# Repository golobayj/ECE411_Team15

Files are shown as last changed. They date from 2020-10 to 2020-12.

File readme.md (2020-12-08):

# ECE411 Team 15 Practicum Project

## Links To Documentation:

### [Project_Design_Specification.pdf](docs/Project_Design_Specification.pdf)

### [Practicum_Project_Ideas.pdf](docs/Practicum_Project_Ideas.pdf)

### [Functional_Decomposition.pdf](docs/Functional_Decomposition.pdf)

### [Modeling.pdf](docs/Modeling.pdf)

### [Test_Plan.pdf](docs/Test_Plan.pdf)

## Final Designs:

### Demo
[Demo Video](https://drive.google.com/file/d/1zAOsdVPUFq6oVJJ1poNx3nirWUGRS5xu/view?usp=sharing)

### Schematic rev 1.1
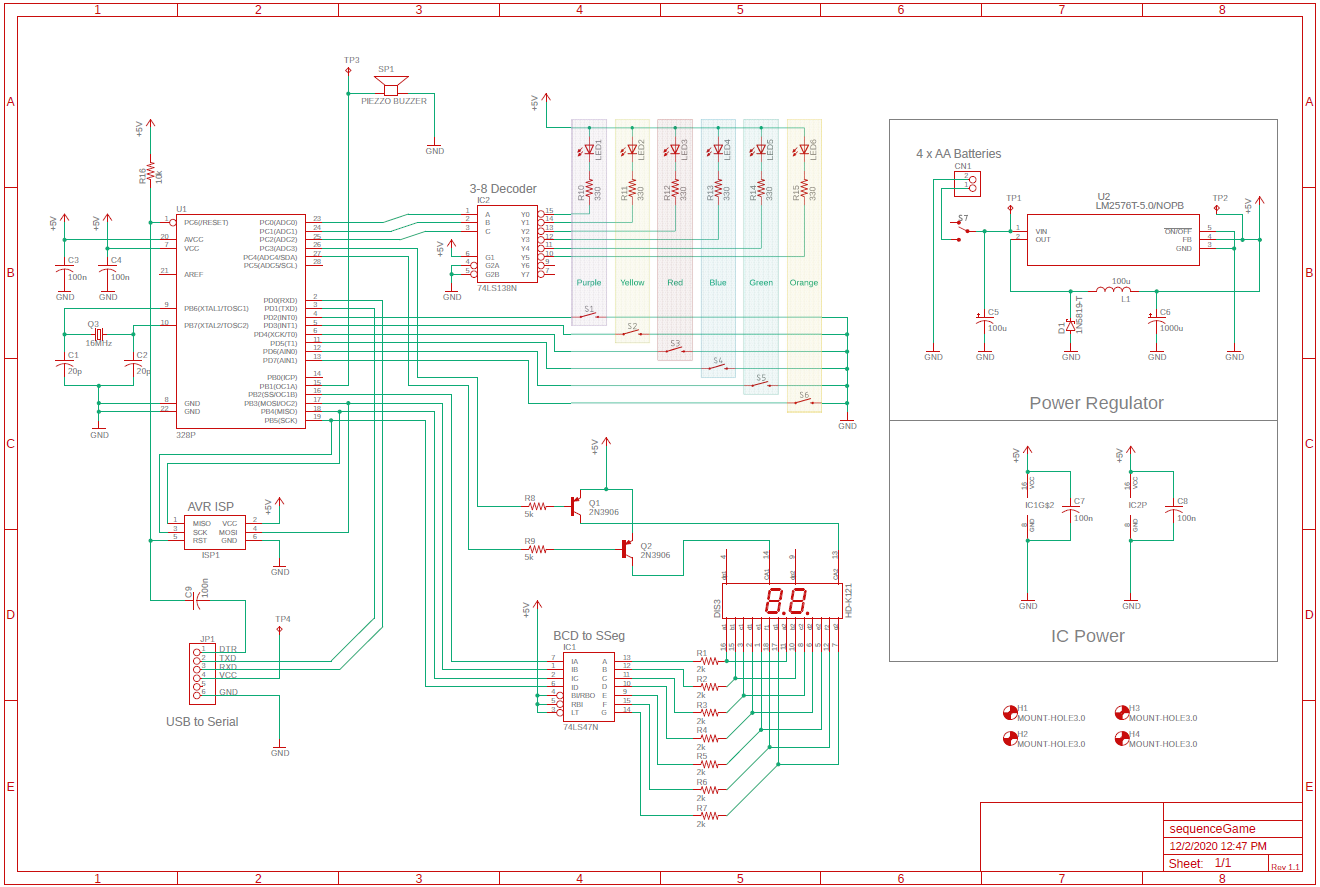
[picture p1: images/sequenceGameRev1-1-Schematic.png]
SchematicRev1-0


### PCB Layout rev 1.0
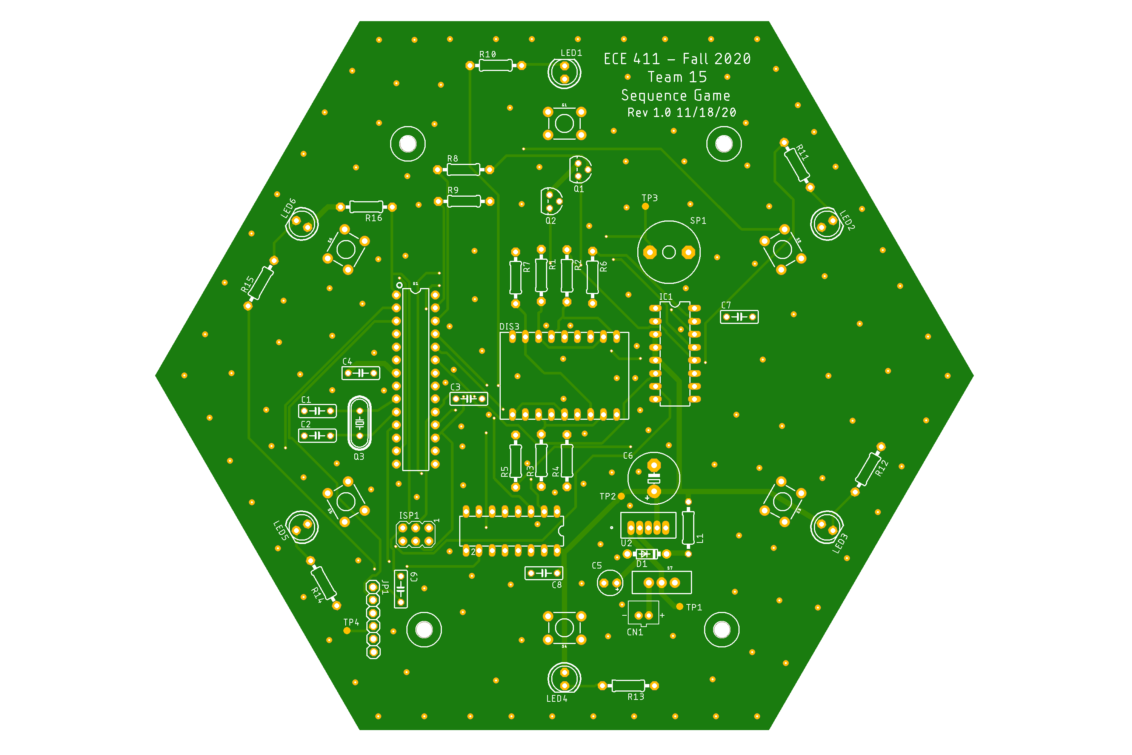
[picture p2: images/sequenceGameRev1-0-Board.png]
BoardRev1-0


### Physical Design
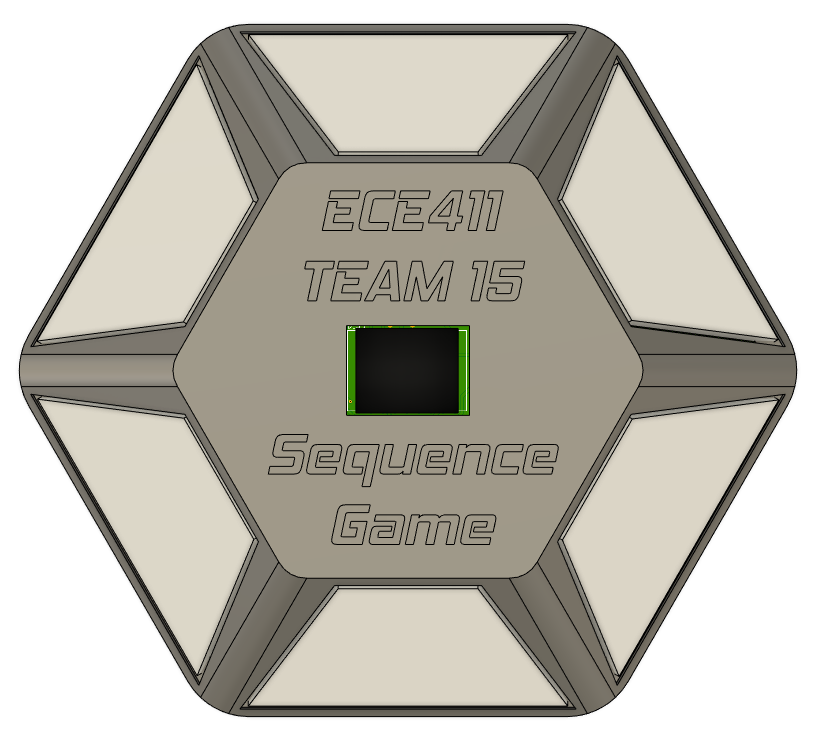
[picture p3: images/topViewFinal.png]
topViewFinal


## Preliminary Designs:

### Breadboard
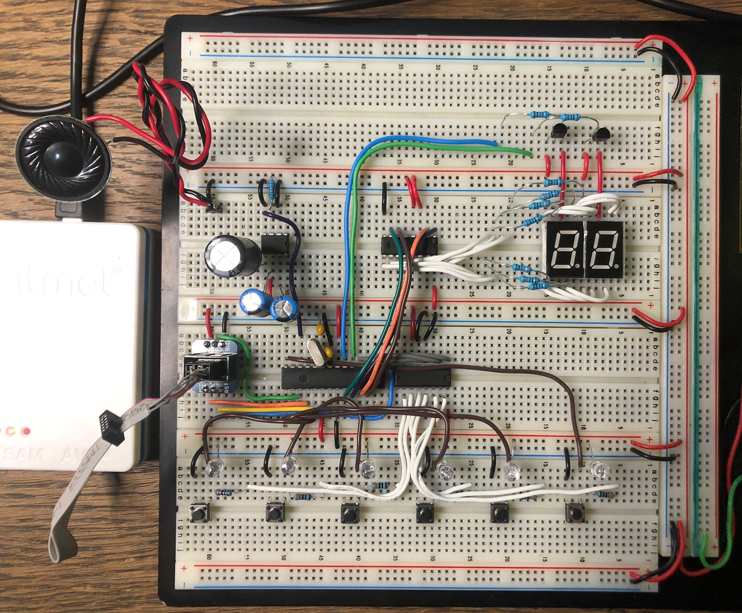
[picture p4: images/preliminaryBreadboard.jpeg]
preliminaryBreadboard


### Physical Design
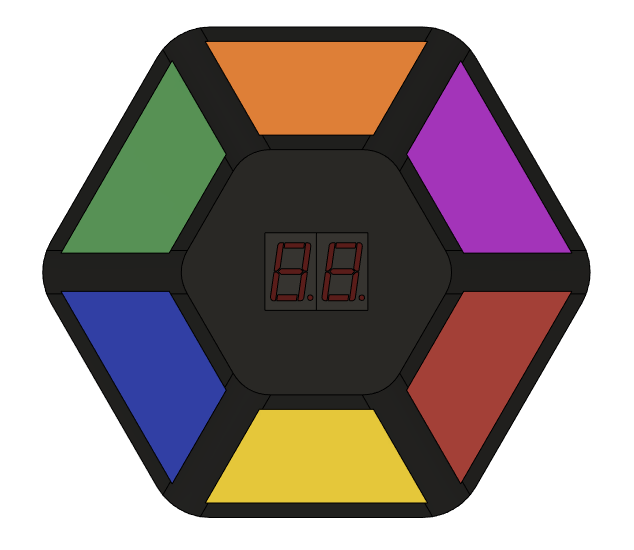
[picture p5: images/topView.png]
topView

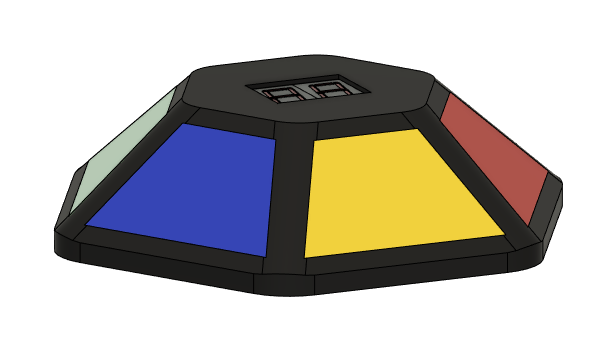
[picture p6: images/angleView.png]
angleView


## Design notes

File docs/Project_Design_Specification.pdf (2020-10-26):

# Team 15 Product Design Specification

## Executive Summary

This project is a simple electronic sequence-based memory game. The game works by displaying a randomly generated sequence of lights and tones that correlate to specific buttons on the device. The game player then attempts to input the same sequence as displayed. The sequence starts at a length of 1 and increases by 1 with each successful matched sequence input by the player. When the player inputs an incorrect sequence the game ends and reports the length of the final correct sequence. Each time the game is played a new random sequence will be generated. Multiplayer mode will allow players to take turns against one another until a player inputs the incorrect sequence.

## Brief Market Analysis

Our product mainly targets parents who are looking for a game that helps their children develop memorization abilities while having fun. Parents and adults may even find it enjoyable and it may have a nostalgic appeal to people familiar with the similar memory game known as Simon.

Similar classic Simon games and other memory related toys that are already out there on the market these would become our primary competition. We decided to make our product with more add-on features to enhance user’s experience with the game compared to classic version. Those features include two extra sides with original design (total of 6 sided compared to 4 sided classic toy), a 7 segment display screen to report player’s score, which is useful to make challenges with friends, various difficulty levels, and multiplayer support.

Additional features may be explored during development. The price range for the Simon games currently found on the market are around $20-30. We estimate the price point for our design to be reasonably estimated at $20. As we finalize the design and components we will adjustment the price accordingly.

## Requirements

The device must be assembled on a 2 or more layer printed circuit board, with a microcontroller to accurately record the user’s inputs and their score. The device will have 6 buttons that will serve as inputs, as well as 6 LEDs which will correspond to each of the buttons.

The system must have a way to accurately keep track of what buttons the user presses. The device must have a randomized sequence of colored buttons each time the game is played. Upon startup, the device may have a short animation using the light displays.

The device should hold the user’s attention for at least one game. The difficulty of the game may be togglable by the user based on their preference or skill level. A multiplayer mode may be included to expand potential gameplay options.

The system will have a speaker to make a distinct sound for each button that is pressed, and the speaker may notify the user of the number of rounds they have successfully passed. The speaker may also be used to play startup tones, or a tone when the user reaches a certain benchmark.

The device must be portable and untethered, using batteries as the source of power for the system. The batteries should last for at least 100 games before needing to be changed out. The device should have an accessible battery compartment for maintenance, while all of the other parts of the device should be permanently fixed onto the device.

As a whole, the device should be durable and able to withstand minor impacts. The unit will also have a power switch to turn the device on and off. The device should be comfortable to hold and use, with rounded edges and corners, and must not cause harm to the user. The device will not infringe on any patents or copyrights.

## System Architecture

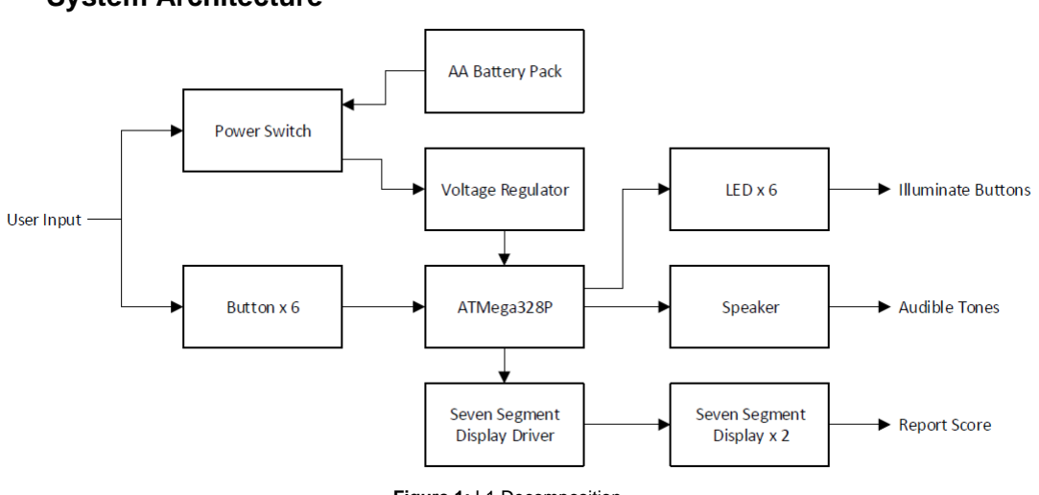
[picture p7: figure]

## Design Specifications

- Processor: Atmel ATMega328P
- Clock: 16MHz external crystal oscillator
- Sensors: 6 x push buttons, power switch
- Actuators: 6 x LEDs, 2 x seven segment displays, speaker
- Power: AA Batteries with voltage regulator
- Firmware: Embedded C
- Development Environment: Atmel Studio 7, Github Repository

Figure 1: L1 Decomposition

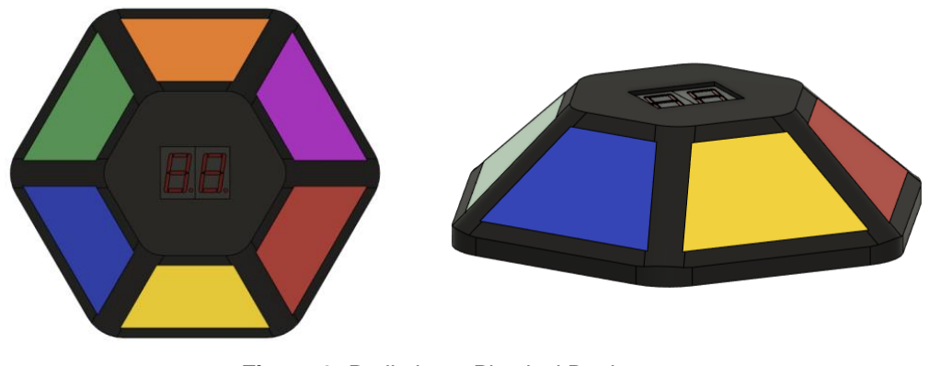
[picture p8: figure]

Figure 2: Preliminary Physical Design

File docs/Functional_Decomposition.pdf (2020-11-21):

ECE 411 | Functional Decomposition | Rev 1.0
Team 15 | | 11/20/20

# Sequence Memory Game: Level 0

## Sequence

## Memory Game

6

Power, Nominal 6V DC

Color Button Inputs

6

Color LED Outputs

Score Display

Audible Tones

Module | Sequence Memory Game
Inputs | Power: Nominal 6V DC provided by 4 x AA Batteries Color Buttons: 6 Buttons corresponding to 6 different colors (red, yellow, orange, green, blue, purple)
Outputs | Audible Tones: Passive piezo buzzer to generate tones that correlate to colors Seven Segment Display: Reports current score to the user Color LEDs: 6 LEDS to correspond to button colors
Functionality | Game that generates a pseudorandom sequence where each element corresponds to a colored LED and tone. Sequence is output starting at length of one and increases in length by one each round. User attempts to input the correct sequence using buttons of corresponding colors to advance to the next round and set the high score.

# Sequence Memory Game: Level 1

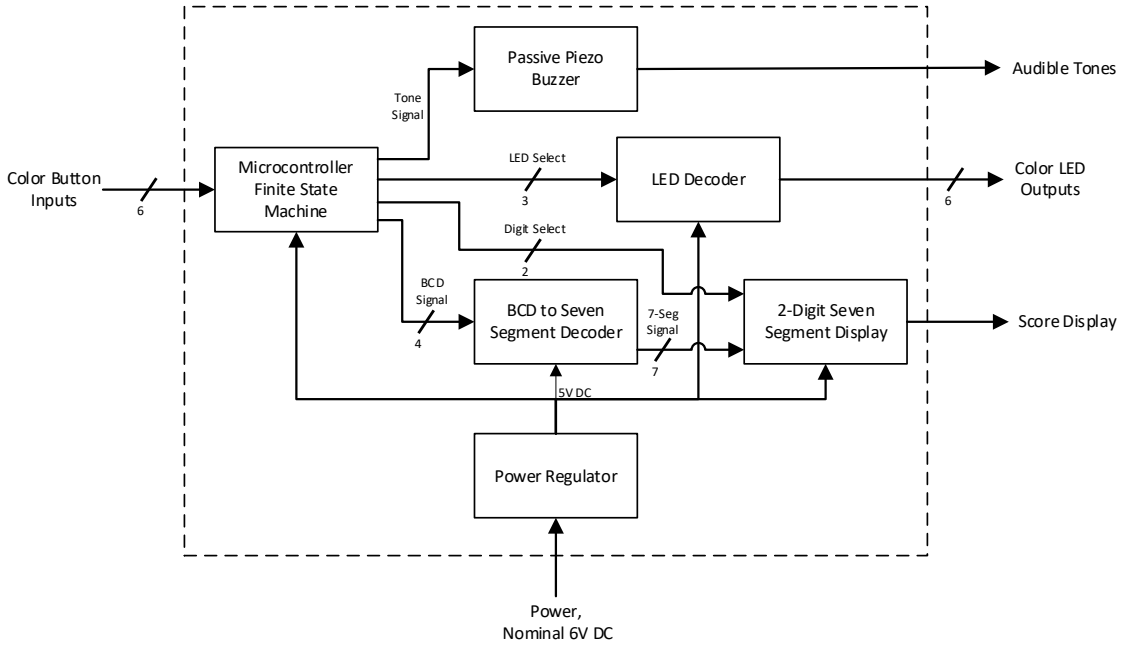
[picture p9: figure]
Microcontroller Finite State Machine; Passive Piezo Buzzer; BCD to Seven Segment Decoder; 2-Digit Seven Segment Display; Power Regulator; LED Decoder; Audible Tones; Color LED Outputs Color Button Inputs; Score Display; Power, Nominal 6V DC; BCD Signal; 7-Seg Signal; Digit Select; LED Select; Tone Signal

# Microcontroller Finite State Machine: Level 1

Microcontroller
Finite State Machine

3

4

6
2

Color Button Inputs

Tone Signal
LED Select
Digit Select
BCD Signal

5V DC

Module | Microcontroller Finite State Machine
Inputs | 5V DC: Regulated 5V DC provided from power regulator module Color Buttons: 6 Buttons corresponding to 6 different colors (red, yellow, orange, green, blue, purple)
Outputs | Tone Signal: Output signal to drive passive piezo buzzer with tones LED Select: 3-bit signal to select appropriate color LED Digit Select: 2-bit signal to select digit of seven segment display BCD Signal: 4-bit BCD signal to output value of seven segment display digit
Functionality | Finite State Machine that is hosted on a microcontroller that drives current state of game. The LED and tone signals are used to output the sequence and acknowledge user input. The seven segment signals are used to report to the user the score of the game. States used are Idle, Start, Display Sequence, Input Sequence, Win, and Lose.

# Passive Piezo Buzzer: Level 1

Tone Signal | Passive Piezo Buzzer | Audible Tones
Module | Passive Piezo Buzzer
Inputs | Tone Signal: Input signal from the microcontroller that drives the tone at a specific frequency
Outputs | Audible Tones: Tones that correspond with the 6 different colored buttons
Functionality | Outputs a tone that is driven by the tone signal from the microcontroller. Tones are of a specific frequency to correspond with a specific color in the sequence or the state of the game. For example, when the player inputs an incorrect sequence a low tone is output.

# LED Decoder: Level 1

LED Decoder

3 | 6
LED Select | Color LED Outputs

5V DC

Module | LED Decoder
Inputs | 5V DC: Regulated 5V DC provided from power regulator module LED Select: 3-bit signal to select appropriate color LED
Outputs | Color LEDs: 6 LEDS to correspond to button colors
Functionality | Decodes 3-bit LED select signal to drive one of 6 colored LEDs that correspond with the respective color of the sequence displayed or the button input by the user.

# BCD to Seven Segment Decoder: Level 1

BCD to Seven Segment
Decoder
4 | 7

5V DC

BCD Signal | Seven Segment Signal
Module | BCD to Seven Segment Decoder
Inputs | 5V DC: Regulated 5V DC provided from power regulator module BCD Signal: 4-bit BCD signal to select value of seven segment display digit
Outputs | Seven Segment Signal: 7-bit signal that corresponds to each segment A-F of the display
Functionality | Decodes binary coded decimal (BCD) to the proper signals needed to drive the seven segment display with the correct corresponding digits of 0-9.

# 2-Digit Seven Segment Display: Level 1

2-Digit Seven Segment
Display

2

7

5V DC

Digit Select

Seven Segment Signal

Score Display

Module | 2-Digit Seven Segment Display
Inputs | 5V DC: Regulated 5V DC provided from power regulator module Digit Select: 2-bit signal to select digit of seven segment display Seven Segment Signal: 7-bit signal that corresponds to each segment A-F of the display
Outputs | Score Display: Outputs the current score of the game to the user
Functionality | Displays the current round or status of the game to the user by illuminating the segments of the display as determined by the BCD to seven segment module. Time division multiplexing is used to drive only one digit at a time fast enough that to the user both digits appear on at the same time.

# Power Regulator: Level 1

Power Regulator

Power,
Nominal 6V DC

5V DC

Module | Power Regulator
Inputs | Power: Nominal 6V DC provided by 4 x AA Batteries
Outputs | 5V DC: Regulated 5V DC to provide power to the other modules
Functionality | Regulates power from batteries to provide consistent 5V power to the modules in the system that require power.

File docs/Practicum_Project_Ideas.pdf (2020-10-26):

# Team 15 Practicum Project Ideas

Our team has decided to pursue Idea 1 below for our practicum project.

Idea 1: 3D "Simon" Says Game

This project is a game that is similar to "Simon Says". The game works by displaying a sequence of lights and tones that correlate to specific buttons on the device. The game player than attempts to input the same sequence as the device displayed. The sequence starts at a length of 1 and increases by 1 with each successful matched sequence input by the player. When the player inputs an incorrect sequence the game ends and reports the length of the final correct sequence. This project will build on this concept by changing the typical plane of 4 buttons and expand it to a 3D shape such as a cube with 6 buttons or a octahedron with 8 sides. The device will use tactile buttons as sensors. The device will actuate a speaker and LEDs. This project can be implemented using an ATMega328P microcontroller.

Sensor: One button for every side of the object

Actuator: One LED for every button and a speaker for audible tones

Controller: ATMega328P

Idea 2: Cup With Temperature Indicator

This project's main purpose is to display the temperature of a cup and/or the liquid its holding so that the user can drink the liquid at its optimal/preferred temperature. The basic design of the project consists of a cup with a temperature sensor inside. The lower part of the cup would be where the microcontroller is stored. When the temperature of the inside of up shifts by a significant amount, the microcontroller would then save the temperature, and display it on a flexible LCD display on the outside of the cup for the user to read.

Sensor: Temperature Sensors

Actuator: LCD (16x2)

Controller: ATMega328P

Idea 3: Digital Clock

This project is aimed to design an automated system of digital clock and temperature thermometer, which assists people’s need on a daily basis to keep track of time. The problem with a regular digital clock is that we have to set the time manually every time the battery runs out or electric outages and also have to look elsewhere/other devices to know the exact time to set to. Therefore, this clock will come in advantage of helping us set the real time automatically with more accuracy. The basic concept of how this clock works is that it takes in measurements from LM335 and time information stored in DS1307, processes in ATMMega32 microcontroller and then displays these values via LCD 16x2 screen. The DS1307 is chosen because it has a built-in feature that can automatically switch to backup supply to keep track of time when power source outage, which assists our purpose of the project.

Sensor: DS1307/1038 serial real-time clock (RTC), LM335 Precision Temperature Sensors

Actuator: LCD (16x2)

Controller: ATMega328P

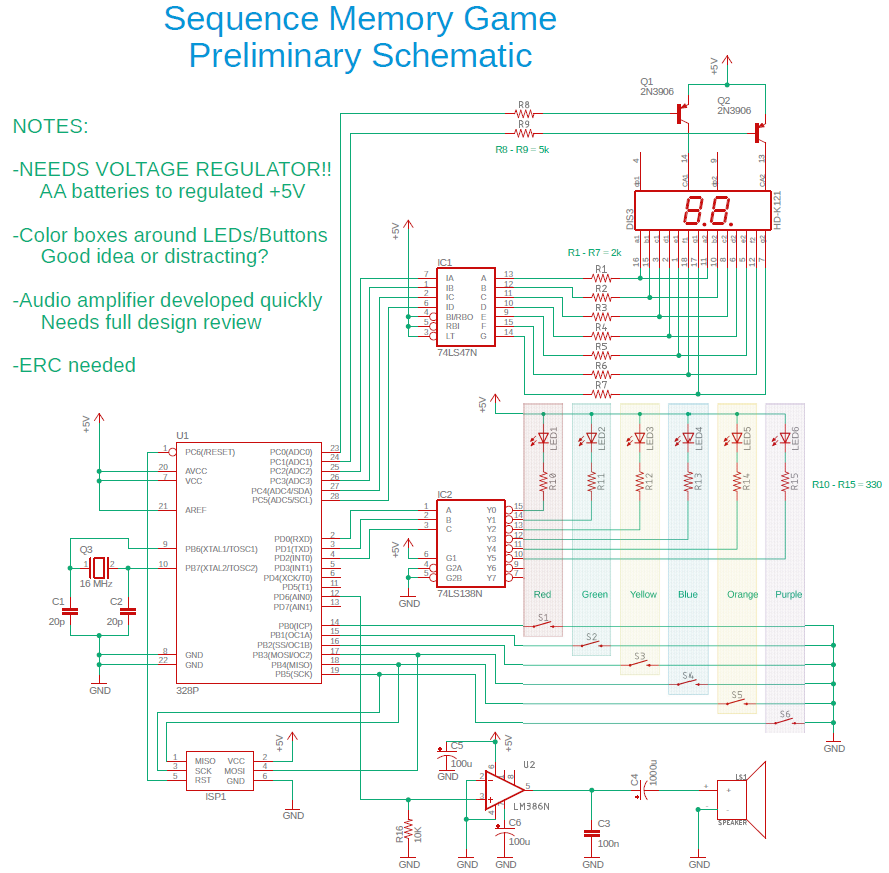
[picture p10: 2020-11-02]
images/preliminarySchematic.png

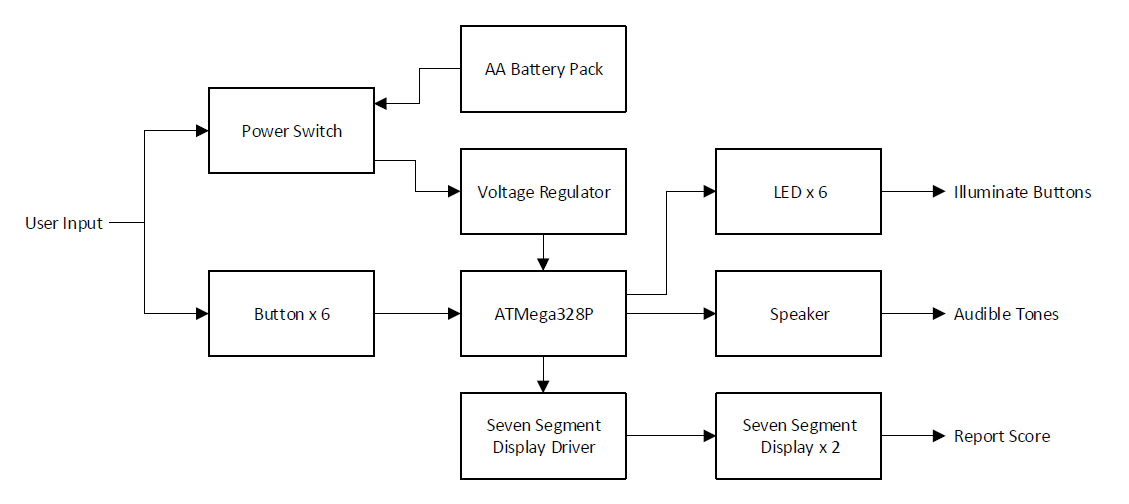
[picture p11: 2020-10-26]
images/L1 Decomp v1.png

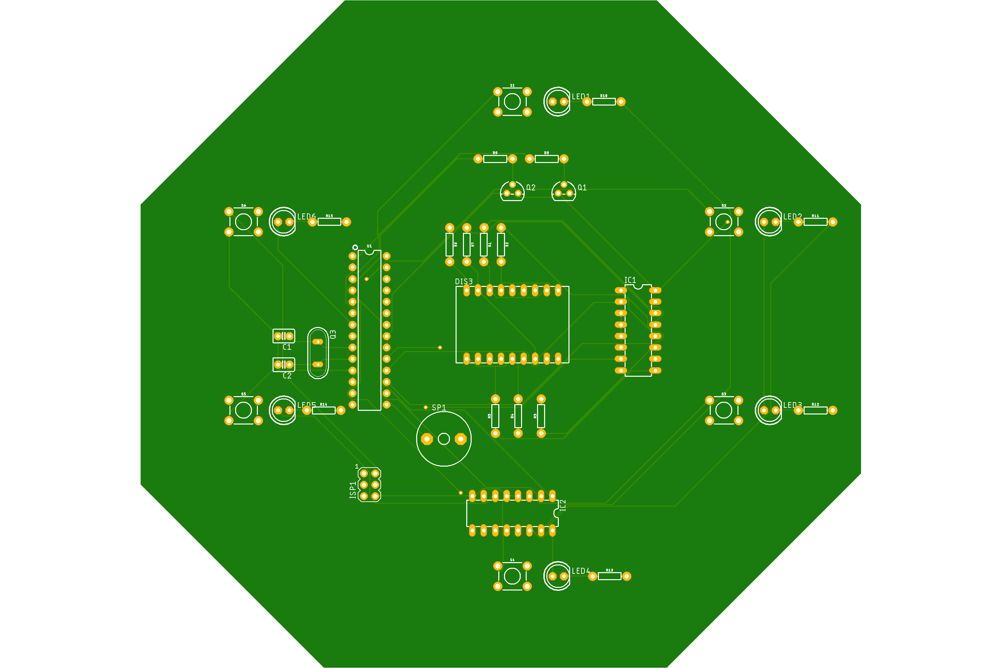
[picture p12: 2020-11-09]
images/prelimPCB.png

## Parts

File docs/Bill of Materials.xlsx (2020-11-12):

Manufacturer Part Number | Manufacturer | Digi-Key Part Number | Quantity | Description
ATMEGA328P-PN | Microchip Technology | ATMEGA328P-PN-ND | 1 | IC MCU 8BIT 32KB FLASH 28DIP
HDSP-521A | Broadcom Limited | 516-3501-ND | 1 | DISPLAY 7SEG 0.56" DBL RED 18DIP
SN74LS138N | Texas Instruments | 296-1639-5-ND | 1 | IC 3-8 LINE DECODER/DEMUX 16-DIP
LM2576T-5.0/NOPB | Texas Instruments | LM2576T-5.0/NOPB-ND | 1 | IC REG BUCK 5V 3A TO220-5
SN74LS47N | Texas Instruments | 296-3712-5-ND | 1 | IC DRVR 7 SEGMENT 16DIP
GT-111P | Soberton Inc. | 433-1020-ND | 1 | AUDIO MAGNETIC XDCR 1-4V TH
S200K25SL0N63L6R | Vishay Beyschlag/Draloric/BC Components | 1265PH-ND | 2 | CAP CER 20PF 1KV SL RADIAL
UVR1C101MDD1TA | Nichicon | 493-6095-1-ND | 1 | CAP ALUM 100UF 20% 16V RADIAL
UPA1C102MPD6TD | Nichicon | 493-4881-1-ND | 1 | CAP ALUM 1000UF 20% 16V RADIAL
RNMF14FTC330R | Stackpole Electronics Inc | S330CACT-ND | 6 | RES 330 OHM 1/4W 1% AXIAL
RNMF14FAD5K10 | Stackpole Electronics Inc | RNMF14FAD5K10CT-ND | 2 | RES 5.1K OHM 1/4W 1% AXIAL
RNMF14FTC2K00 | Stackpole Electronics Inc | S2KCACT-ND | 7 | RES 2K OHM 1/4W 1% AXIAL
K104K15X7RF5TL2 | Vishay Beyschlag/Draloric/BC Components | BC1084CT-ND | 3 | CAP CER 0.1UF 50V X7R RADIAL
S200K25SL0N63L6R | Vishay Beyschlag/Draloric/BC Components | 1265PH-ND | 2 | CAP CER 20PF 1KV SL RADIAL

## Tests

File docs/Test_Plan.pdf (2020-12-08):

Test Plan Development for Sequence Game | 1

# Test Plan Development for Sequence Game

## Revision 1.0

### December 7, 2020

### Team 15

## Authors:

Luis Nadora | lnadora@pdx.edu
Minh Le | mql2@pdx.edu
Jon Golobay | golobay@pdx.edu
Yida Liu | yida@pdx.edu

# Table of Contents

### 1.0 REFERENCE DOCUMENTS

1.1 | Design Documentation
| ● System Specification Rev.1.0
| ● Block Diagram Rev.1.0
| ● Schematic Rev.1.1
| ● Functional Decomposition Rev.1.0

### 2.0 OBJECTIVES

2.1 | Unit Tests
2.2 | Integration Tests
2.3 | Parametric Tests
2.4 | Functional Tests
2.5 | Environmental Tests

### 3.0 PRETEST PREPARATION

3.1 | Testing Equipment
3.2 | Testing Components
3.3 | Testing Software

### 4.0 SYSTEM TESTS

4.1 | Button Test
4.2 | LED Test
4.3 | Speaker Frequency Range Test
4.4 | 7-Segment Display Test
4.5 | Button LED Integration Test
4.6 | Battery Test
4.7 | State Machine Test
4.8 | Speaker Decibel Test

# 1.0 REFERENCE DOCUMENTS

## 1.1 Design Documentation

- Project Design Specification Rev.1.0
- Schematic Rev.1.1
- Functional Decomposition Rev.1.0
- Modeling.pdf Rev.1.0

# 2.0 OBJECTIVES

## 2.1 Unit Tests

- Buttons Work Properly
- LEDs Light Up Properly
- Speaker can output a set range of frequencies
- 7-Segment display can display an output of numbers from 0 through 99

## 2.2 Integration Test

- Make sure the LED activated by the correct button

## 2.3 Parametric Test

- Power/Battery lasts long enough to play 100 games

## 2.4 Functional Tests

- Make game state machine is operating properly

## 2.5 Environmental Tests

- Decibel level of the speaker

# 3.0 PRETEST PREPARATION

## 3.1 Testing Equipment

- Oscilloscope
- Multimeter
- AA Batteries (4)
- AVR programmer (ATMEL-ICE Programmer)

## 3.2 Testing Components

- PCB Version 1.0

## 3.3 Testing Software

- ATMEL Studio 7

# 4.0 SYSTEM TESTS

## 4.1 Button Test

Test that each button is being accepted as an input by the microcontroller by programming one of the on-board LEDs to turn on when each button is pressed.

## 4.2 LED Test

Test that each LED is able to illuminate by programming each LED to light up in a sequence.

## 4.3 Speaker Frequency Range Test

Test that the speaker is able to output the correct tones needed for the game by programming the microcontroller to have the speaker output tones within a certain range of frequencies.

## 4.4 7-Segment Display Test

Test that all segments of the display work correctly by programming the microcontroller to display the numbers 00 through 99 on the 7-segment display.

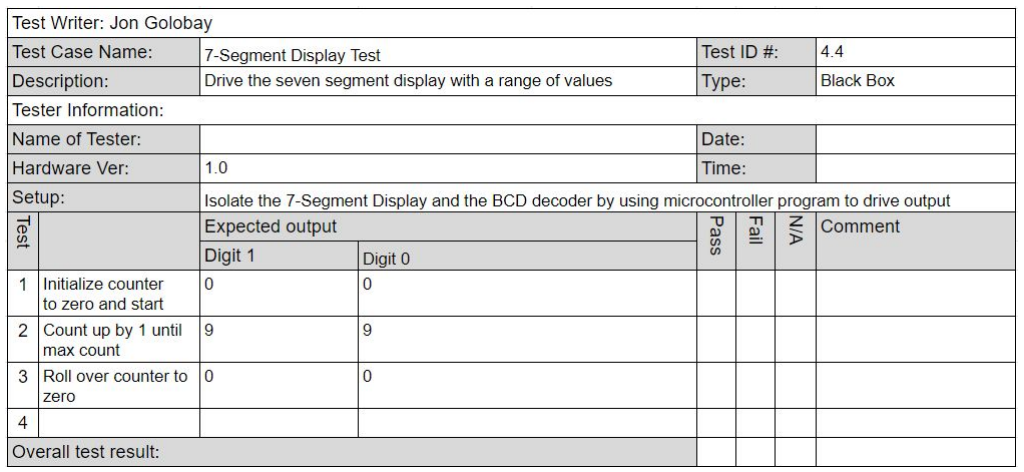
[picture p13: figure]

## 4.5 Button LED integration Test

Test that the press of a button corresponds to the correct LED by programming the microcontroller to have the LED light up when the corresponding button is pressed.

## 4.6 Battery Test

Test that the battery is able to last for 100 games by programming the microcontroller to run a simulation where a user is able to play through 99 rounds of the game. Based on the power consumption of one 99-round game, determine whether the battery power (four AA batteries) would be able to supply enough power for 100 games to be played on the device.

## 4.7 State Machine Test

Test that the game state machine is working correctly by programming the microcontroller to walk through each possible sequence of states in the finite state machine.

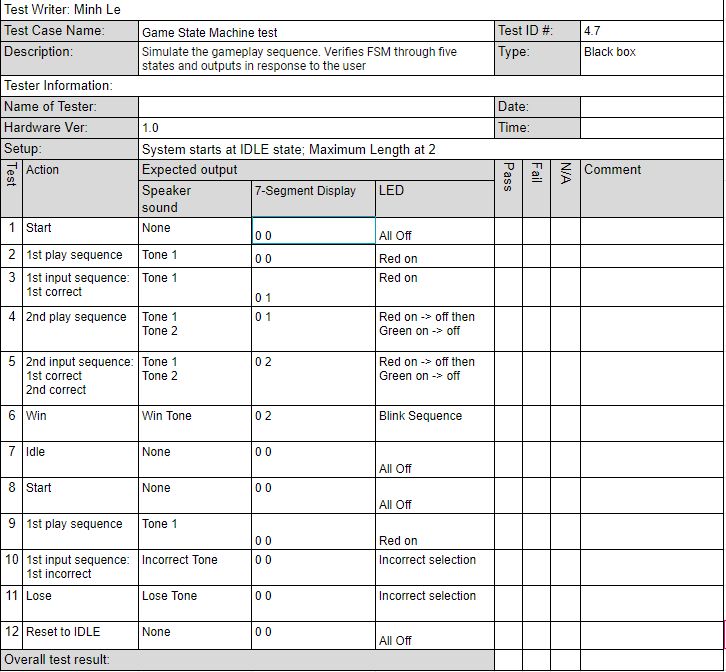
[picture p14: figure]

## 4.8 Speaker Decibel Test

Test that the speaker is audible in most environments without being damaging after long periods of time. Use a sound level meter to make sure that the speaker is within the 50-70 decibel range.

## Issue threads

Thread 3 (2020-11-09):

Add Power Source to Schematic/PCB

golobayj, 2020-11-09:
Schematic and PCB are currently missing the power source.  Parts are arriving for testing soon to determine selection.

Will need to add:
- Power switch
- Voltage regulator
- Battery source (4xAA)

golobayj, 2020-11-19:
Power source issues resolved(voltage regulator added, switch added, battery source added)

Closed 2020-11-19.

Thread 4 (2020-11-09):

Revise Schematic and PCB Layout

golobayj, 2020-11-09:
PCB Layout was fast and rough and needs significant revisions.  Needs to be done prior to design review with another team which is due by Thursday 11/21.

golobayj, 2020-11-19:
Revisions completed, board reviews completed, board sent to OSH Park for manufacturing

Closed 2020-11-19.

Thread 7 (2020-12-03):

Test Plan Development

golobayj, 2020-12-03:
We need to develop our test plans:

Some Ideas:
- Button Tests: Program with button interrupts
- LED Output Test: Program to drive all the different colors
- Speaker Output Tests: Program to test timers for differing frequencies
- Seven Segment Display Test (test timer for time division multiplexing)
- Game State Machine Test: Essentially testing the whole game
- Power Supply Test: Monitor battery output over time through voltage regulator? Could use program to drive all LEDS and SSD segments and tone to drain battery.  Meet requirements document of play 100 games?

Closed 2020-12-08.

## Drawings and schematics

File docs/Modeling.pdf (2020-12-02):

ECE 411 | Sequence Game | Rev 1.0
Team 15 | Modeling | 11/27/20

1

# UML Class Diagram

### Sequence

-length(int)
-currentColor(int)
-currentRound(int)
+seedSequence()
+generateSequence()

### Seven Segment Display

-digitValue0(int)
-digitValue1(int)
+displayDigits()
+countValueUp()
+setValue()

### Button

-color(int)
+buttonISR()

### Speaker

-frequency(int)
+toneISR()
+toneOn()
+toneOff()

### Game State Machine

-currentState(int)
-nextState(int)
-maxRounds(int)

### LED

-color(int)
+driveLED()

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
1 | 1

### -sent to

### -receives

### -contains

### -part of

### -receives

### -sent to

### -sent to

### -sent to

# State Diagram

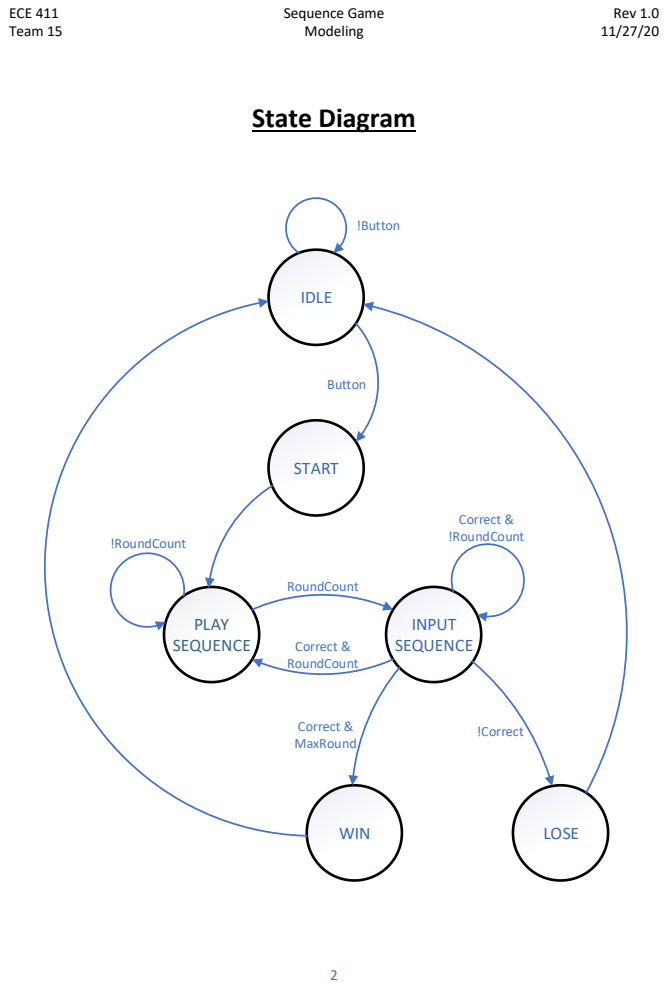
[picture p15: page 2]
ECE 411; Sequence Game; Rev 1.0; Team 15; Modeling; IDLE; START; INPUT SEQUENCE; PLAY SEQUENCE; WIN; LOSE; !Button; Button; !RoundCount; RoundCount; Correct & !RoundCount; Correct & RoundCount; !Correct Correct & MaxRound

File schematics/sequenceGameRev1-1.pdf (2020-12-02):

# 3-8 Decoder

# 4 x AA Batteries

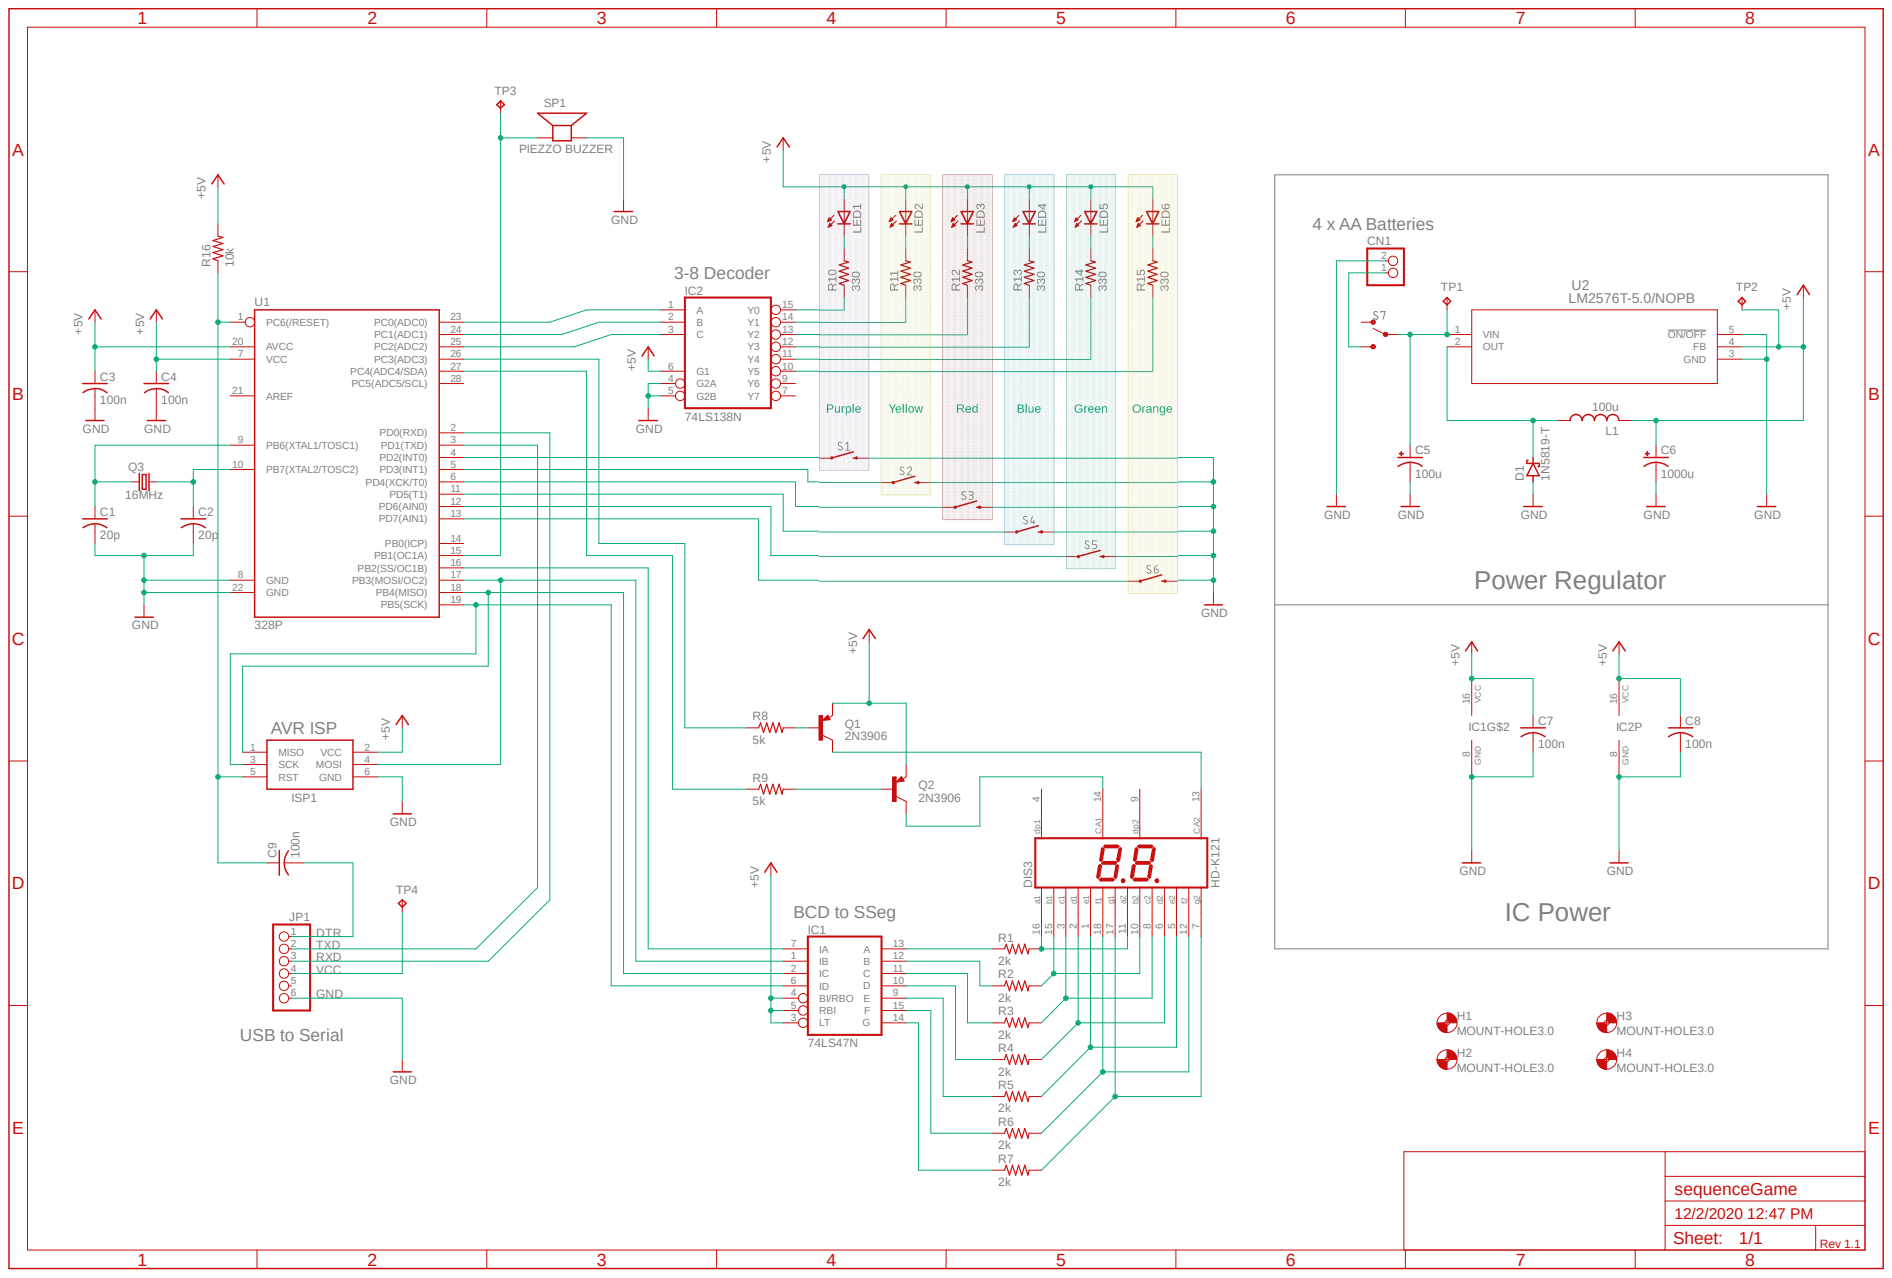
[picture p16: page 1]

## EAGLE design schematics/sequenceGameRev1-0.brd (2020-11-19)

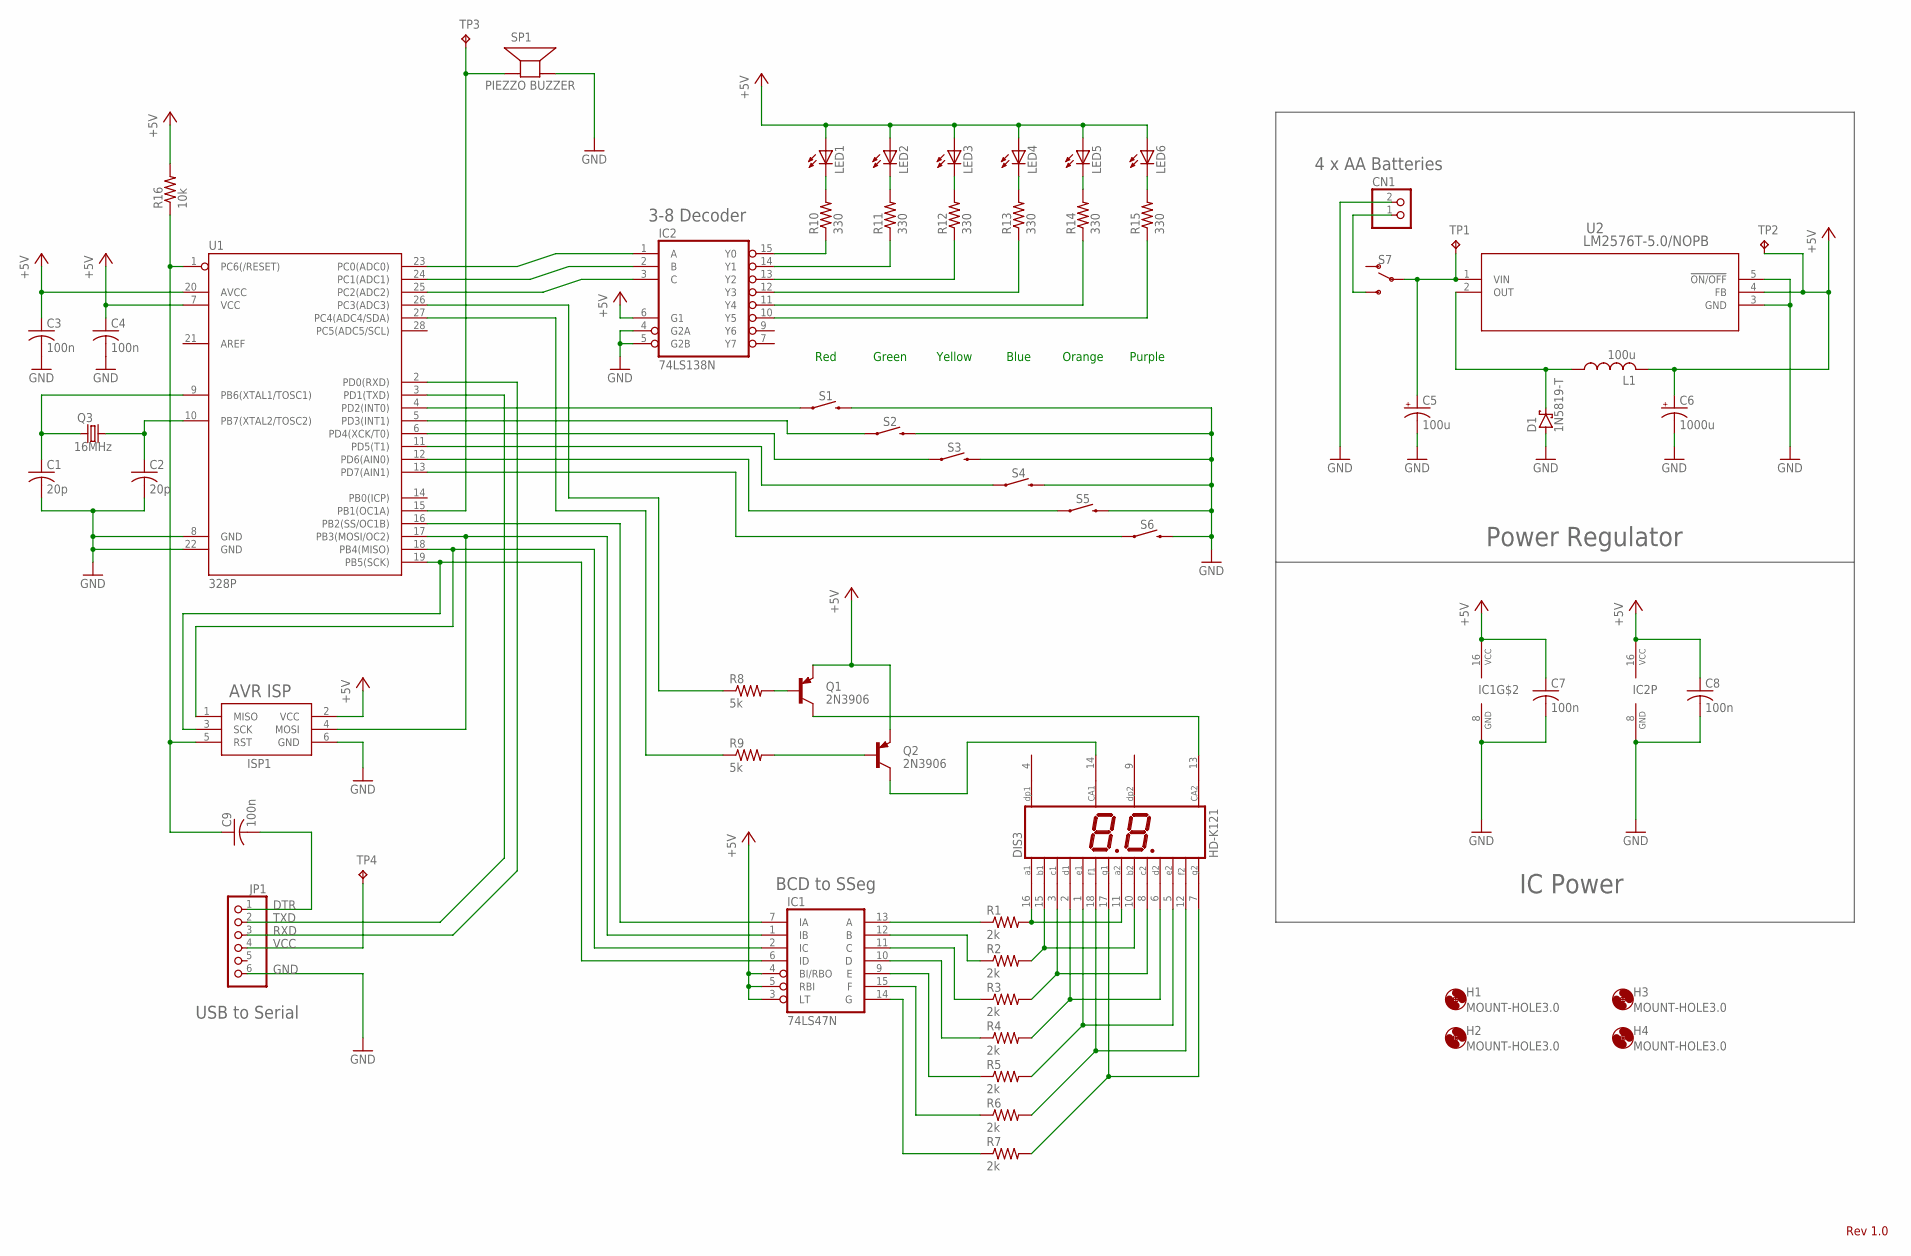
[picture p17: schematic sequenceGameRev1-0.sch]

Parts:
C1, C2: 20p; C050-025X075
C3, C4, C7, C8, C9: 100n; C050-025X075
C5: 100u; E2,5-5
C6: 1000u; E5-10,5
CN1: JST_2PIN-THM; JST-PH-2-THM
D1: 1N5819-T; DO41-7.6
DIS3: HD-K121; HDSP-R
H1, H2, H3, H4: MOUNT-HOLE3.0; 3,0
IC1: 74LS47N; DIL16
IC2: 74LS138N; DIL16
ISP1: AVRISP-6; AVRISP
JP1: PINHD-1X6; 1X06
L1: 100u; 0207/10
LED1, LED2, LED3, LED4, LED5, LED6: LED5MM
Q1, Q2: 2N3906; TO92
Q3: 16MHz; HC49/S
R1, R2, R3, R4, R5, R6, R7: 2k; 0207/10
R8, R9: 5k; 0207/10
R10, R11, R12, R13, R14, R15: 330; 0207/10
R16: 10k; 0207/10
S1, S2, S3, S4, S5, S6: MOMENTARY-SWITCH-SPST-PTH-6.0MM; TACTILE_SWITCH_PTH_6.0MM
S7: SWITCH-SPDT-PTH-11.6X4.0MM; SWITCH_SPDT_PTH_11.6X4.0MM
SP1: PIEZZO BUZZER; AL60P
TP1, TP2, TP3, TP4: TPB1,27; B1,27
U1: 328P; DIP28
U2: LM2576T-5.0/NOPB; T05A_TEX

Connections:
+5V: C3.1, C4.1, C6.+, C7.1, C8.1, IC1.3 (LT), IC1.4 (BI/RBO), IC1.5 (RBI), IC1.16 (VCC), IC2.6 (G1), IC2.16 (VCC), ISP1.2 (VCC), L1.2, LED1.A, LED2.A, LED3.A, LED4.A, LED5.A, LED6.A, Q1.3 (E), Q2.3 (E), R16.2, TP2.TP, U1.7 (VCC), U1.20 (AVCC), U2.4 (FB)
BATT_IN: CN1.1 (2), S7.3 (S)
DTR: C9.2, JP1.1
GND: C1.2, C2.2, C3.2, C4.2, C5.-, C6.-, C7.2, C8.2, CN1.2 (1), D1.A, IC1.8 (GND), IC2.4 (G2A), IC2.5 (G2B), IC2.8 (GND), ISP1.6 (GND), JP1.6, S1.3 (2), S2.3 (2), S3.3 (2), S4.3 (2), S5.3 (2), S6.3 (2), SP1.2 (-), U1.8 (GND), U1.22 (GND), U2.3 (GND), U2.5 (!ON/OFF)
LDO_IN: C5.+, S7.2, TP1.TP, U2.1 (VIN)
LDO_OUT: D1.C, L1.1, U2.2 (OUT)
unnamed: DIS3.10 (B2), DIS3.15 (B1), R2.2
unnamed: SP1.1 (+), TP3.TP, U1.15 (PB1(OC1A))
unnamed: DIS3.3 (C1), DIS3.8 (C2), R3.2
unnamed: DIS3.2 (D1), DIS3.6 (D2), R4.2
unnamed: DIS3.1 (E1), DIS3.5 (E2), R5.2
unnamed: DIS3.12 (F2), DIS3.18 (F1), R6.2
unnamed: IC1.13 (A), R1.1
unnamed: IC1.12 (B), R2.1
unnamed: IC1.11 (C), R3.1
unnamed: IC1.10 (D), R4.1
unnamed: IC1.9 (E), R5.1
unnamed: Q2.2 (B), R9.2
unnamed: R8.1, U1.26 (PC3(ADC3))
unnamed: Q1.2 (B), R8.2
unnamed: DIS3.7 (G2), DIS3.17 (G1), R7.2
unnamed: C2.1, Q3.1, U1.10 (PB7(XTAL2/TOSC2))
unnamed: IC2.15 (Y0), R10.1
unnamed: IC2.14 (Y1), R11.1
unnamed: IC2.13 (Y2), R12.1
unnamed: IC2.12 (Y3), R13.1
unnamed: IC2.11 (Y4), R14.1
unnamed: IC2.10 (Y5), R15.1
unnamed: C1.1, Q3.2, U1.9 (PB6(XTAL1/TOSC1))
unnamed: LED1.K (C), R10.2
unnamed: LED2.K (C), R11.2
unnamed: LED3.K (C), R12.2
unnamed: LED4.K (C), R13.2
unnamed: LED5.K (C), R14.2
unnamed: LED6.K (C), R15.2
unnamed: IC1.15 (F), R6.1
unnamed: S4.1, U1.11 (PD5(T1))
unnamed: S5.1, U1.12 (PD6(AIN0))
unnamed: IC1.6 (ID), ISP1.3 (SCK), U1.19 (PB5(SCK))
unnamed: S6.1, U1.13 (PD7(AIN1))
unnamed: IC1.2 (IC), ISP1.1 (MISO), U1.18 (PB4(MISO))
unnamed: S2.1, U1.5 (PD3(INT1))
unnamed: IC2.1 (A), U1.23 (PC0(ADC0))
unnamed: IC2.2 (B), U1.24 (PC1(ADC1))
unnamed: S3.1, U1.6 (PD4(XCK/T0))
unnamed: IC1.7 (IA), U1.16 (PB2(SS/OC1B))
unnamed: IC1.1 (IB), ISP1.4 (MOSI), U1.17 (PB3(MOSI/OC2))
unnamed: R9.1, U1.27 (PC4(ADC4/SDA))
unnamed: DIS3.13 (CA2), Q1.1 (C)
unnamed: IC2.3 (C), U1.25 (PC2(ADC2))
unnamed: DIS3.14 (CA1), Q2.1 (C)
unnamed: DIS3.11 (A2), DIS3.16 (A1), R1.2
unnamed: IC1.14 (G), R7.1
unnamed: S1.1, U1.4 (PD2(INT0))
RESET: C9.1, ISP1.5 (RST), R16.1, U1.1 (PC6(/RESET))
RXD: JP1.3, U1.2 (PD0(RXD))
TXD: JP1.2, U1.3 (PD1(TXD))
VCC: JP1.4, TP4.TP

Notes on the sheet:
Red
Green
Yellow
Blue
Orange
Purple
3-8 Decoder
BCD to SSeg
4 x AA Batteries
AVR ISP
USB to Serial
Power Regulator
IC Power
Rev 1.0

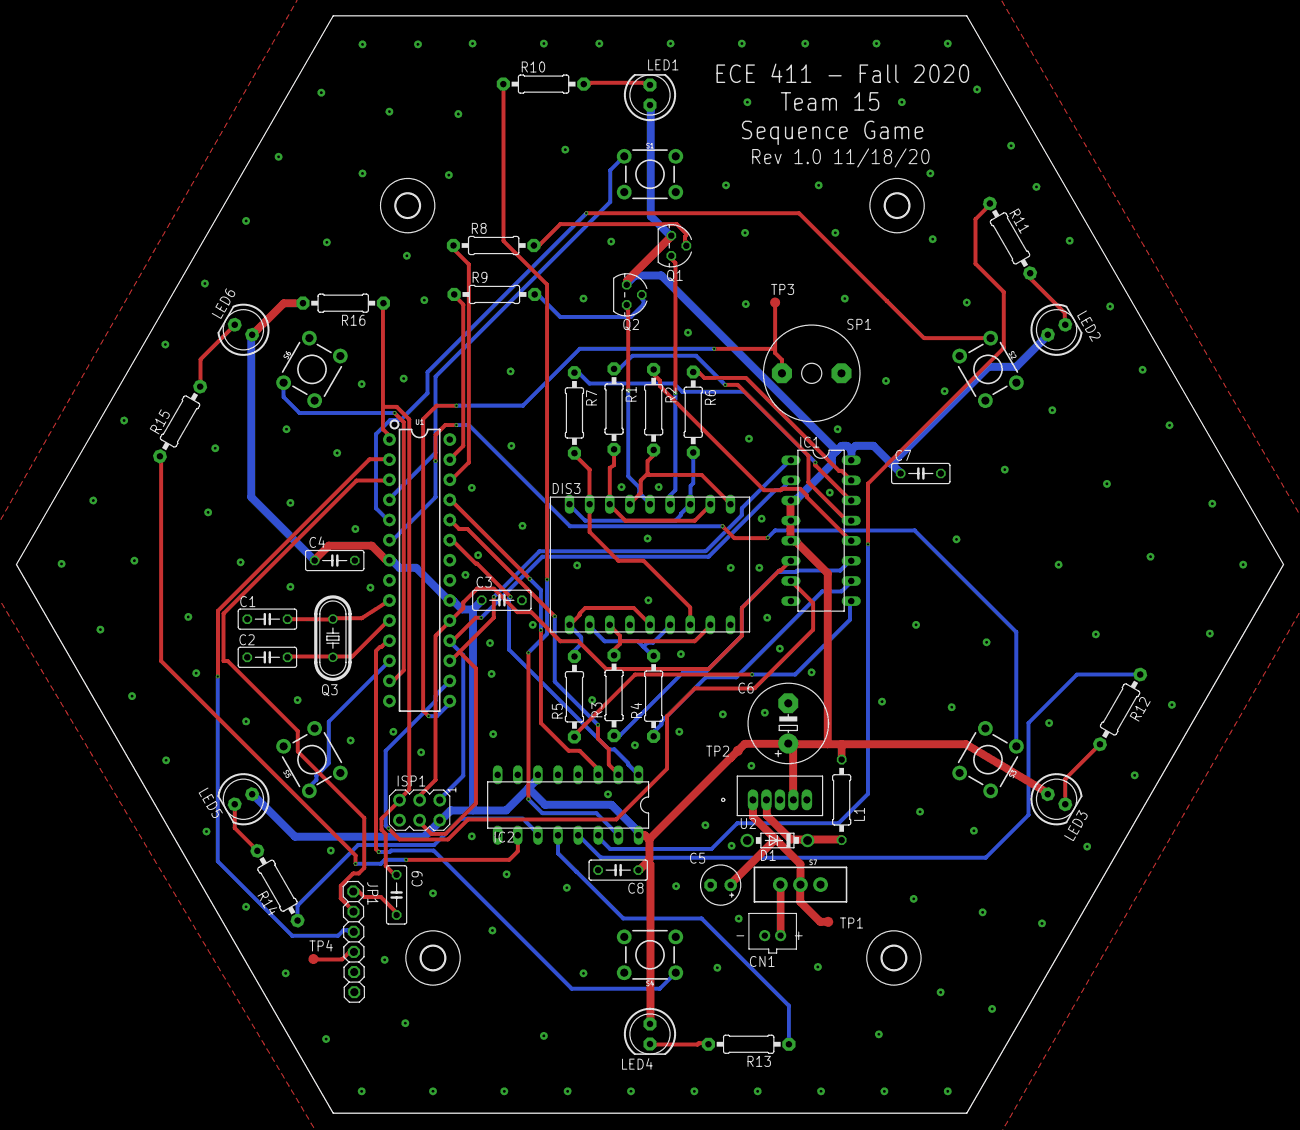
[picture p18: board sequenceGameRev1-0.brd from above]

Board: 2 copper layers, 160.0 x 138.6 mm, 60 parts (0 on the bottom side), 58 nets.

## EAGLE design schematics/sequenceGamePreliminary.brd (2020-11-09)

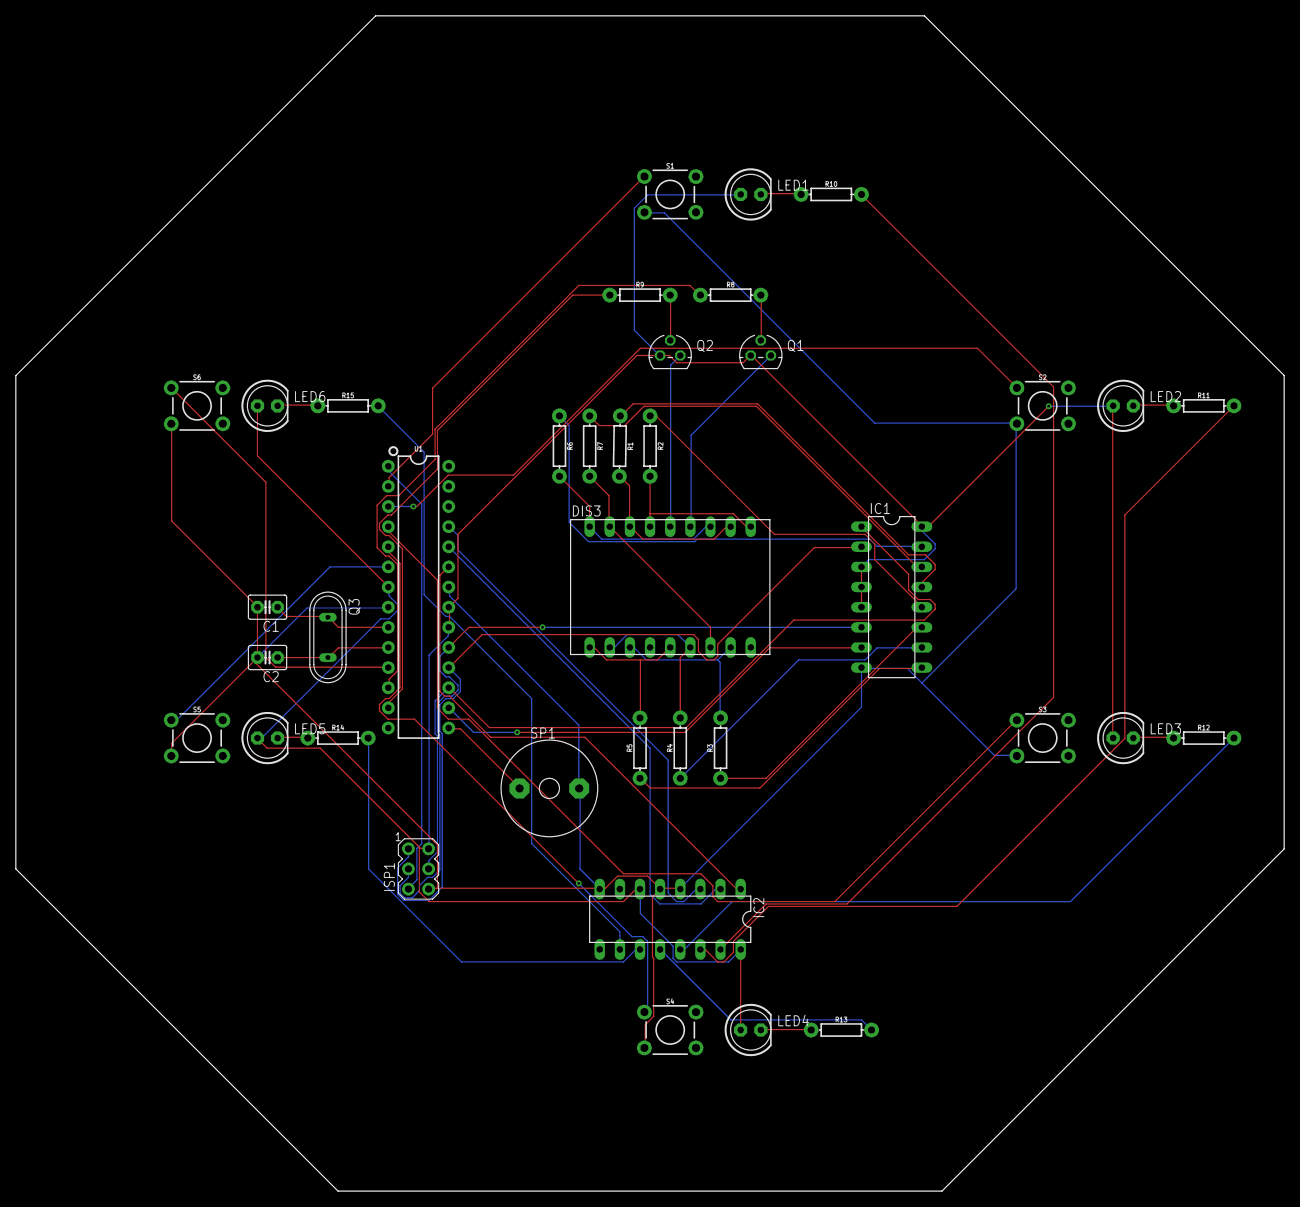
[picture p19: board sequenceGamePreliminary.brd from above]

Board: 2 copper layers, 160.0 x 148.3 mm, 38 parts (0 on the bottom side), 51 nets.

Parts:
C1, C2: 20p; C2.5-3
DIS3: HD-K121; HDSP-R
IC1: 74LS47N; DIL16
IC2: 74LS138N; DIL16
ISP1: AVRISP-6; AVRISP
LED1, LED2, LED3, LED4, LED5, LED6: LED5MM
Q1, Q2: 2N3906; TO92
Q3: QS
R1, R2, R3, R4, R5, R6, R7, R8, R9, R10, R11, R12, R13, R14, R15: AXIAL-0.3
S1, S2, S3, S4, S5, S6: MOMENTARY-SWITCH-SPST-PTH-6.0MM; TACTILE_SWITCH_PTH_6.0MM
SP1: SPEAKER/AL60P; AL60P
U1: 328P; DIP28

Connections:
+5V: IC1.3, IC1.4, IC1.5, IC1.16, IC2.6, IC2.16, ISP1.2, LED1.A, LED2.A, LED3.A, LED4.A, LED5.A, LED6.A, Q1.3, Q2.3, U1.7, U1.20, U1.21
GND: C1.2, C2.2, IC1.8, IC2.4, IC2.5, IC2.8, ISP1.6, S1.3, S2.3, S3.3, S4.3, S5.3, S6.3, SP1.2, U1.8, U1.22
unnamed: DIS3.10, DIS3.15, R2.P$2
unnamed: SP1.1, U1.15
unnamed: DIS3.3, DIS3.8, R3.P$2
unnamed: DIS3.2, DIS3.6, R4.P$2
unnamed: DIS3.1, DIS3.5, R5.P$2
unnamed: DIS3.12, DIS3.18, R6.P$2
unnamed: IC1.13, R1.P$1
unnamed: IC1.12, R2.P$1
unnamed: IC1.11, R3.P$1
unnamed: IC1.10, R4.P$1
unnamed: IC1.9, R5.P$1
unnamed: Q2.2, R9.P$2
unnamed: R8.P$1, U1.12
unnamed: Q1.2, R8.P$2
unnamed: DIS3.7, DIS3.17, R7.P$2
unnamed: C2.1, Q3.2, U1.10
unnamed: IC2.15, R10.P$2
unnamed: IC2.14, R11.P$2
unnamed: IC2.13, R12.P$2
unnamed: IC2.12, R13.P$2
unnamed: IC2.11, R14.P$2
unnamed: IC2.10, R15.P$2
unnamed: C1.1, Q3.1, U1.9
unnamed: LED1.K, R10.P$1
unnamed: LED2.K, R11.P$1
unnamed: LED3.K, R12.P$1
unnamed: LED4.K, R13.P$1
unnamed: LED5.K, R14.P$1
unnamed: LED6.K, R15.P$1
unnamed: IC1.15, R6.P$1
unnamed: S4.1, U1.5
unnamed: S5.1, U1.6
unnamed: IC1.6, ISP1.3, U1.19
unnamed: ISP1.5, U1.1
unnamed: S6.1, U1.11
unnamed: S1.1, U1.2
unnamed: IC1.2, ISP1.1, U1.18
unnamed: S2.1, U1.3
unnamed: IC2.1, U1.23
unnamed: IC2.2, U1.24
unnamed: S3.1, U1.4
unnamed: IC1.7, U1.16
unnamed: IC1.1, ISP1.4, U1.17
unnamed: R9.P$1, U1.13
unnamed: DIS3.13, Q1.1
unnamed: IC2.3, U1.25
unnamed: DIS3.14, Q2.1
unnamed: DIS3.11, DIS3.16, R1.P$2
unnamed: IC1.14, R7.P$1

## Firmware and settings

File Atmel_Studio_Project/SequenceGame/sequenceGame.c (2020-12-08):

/*
 * sequenceGame.c
 *
 * Author : Jon Golobay
 */ 
#ifndef F_CPU					// if F_CPU was not defined in Project -> Properties
#define F_CPU 16000000UL		// define it now as 16 MHz unsigned long
#endif

#include <avr/io.h>
#include <avr/interrupt.h>
#include <util/delay.h>	
#include "sevenSegment.h"

#define ledA PC0
#define ledB PC1
#define ledC PC2

#define digit0 PC3
#define digit1 PC4

#define sSegA PB2	
#define sSegB PB3	
#define sSegC PB4
#define sSegD PB5

#define buttonPur PD2
#define buttonYel PD3
#define buttonRed PD4		
#define buttonBlu PD5
#define buttonGre PD6
#define buttonOra PD7

#define speaker PB1

enum color{PURPLE, YELLOW, RED, BLUE, GREEN, ORANGE, OFF};
enum state{idle, start, playSequence, inputSequence, win, lose};
	
static uint8_t randomSeed = 0, *randomSeedPtr = &randomSeed;

volatile uint8_t toneCount = 0xFF, *toneCountPtr = &toneCount;

static enum state gameState = idle;
volatile static enum color input, lastInput;
volatile uint8_t roundCount = 0;
volatile uint8_t inputCounter = 0;

#define MAX_SEQ_LENGTH 5
uint8_t randomSequence[MAX_SEQ_LENGTH];

sSeg_t disp = {sSegA, sSegB, sSegC, sSegD, digit0, digit1, 0, 0, 0};

// Function Prototypes
void driveOutput(enum color col);
void displaySequence(int length, uint8_t sequence[]);
enum state acceptInput(uint8_t length);
void generateSequence(uint8_t length, uint8_t *seed);
void seedSequence(uint8_t *seed);
void toneOn(uint8_t count);
void toneOff(void);

int main(void)
{	
	// setup speaker as output
	DDRB |= (1 << speaker);
	
	// setup timer 1 for speaker
	TCCR1A = 0x00; // Normal operation
	TCCR1B = (1<<CS11)|(1<<CS10)|(1<<WGM12)|(1<<ICNC1); // 256x prescaler, MODE 4
	TCCR1C = 0x80;

	// Setup seven segment display outputs
	DDRC |= (1 << digit0) | (1 << digit1);
	DDRB |= (1 << sSegA) | (1 << sSegB) | (1 << sSegC) | (1 << sSegD);
	PORTB |= (1 << sSegA) | (1 << sSegB) | (1 << sSegC) | (1 << sSegD);

	// setup timer 2 for seven segment time division multiplexing
	TCCR2A = 0b00000010;
	TCCR2B = 0b00000101;
	TIMSK2 = 0b00000010;
	OCR2A = 0b01000100;
		
	// setup buttons as inputs with pull-ups
	DDRD &= ~(1 << buttonPur) | ~(1 << buttonYel) | ~(1 << buttonRed) | ~(1 << buttonBlu) | ~(1 << buttonGre) | ~(1 << buttonOra);
	PORTD |= (1 << buttonPur) | (1 << buttonYel) | (1 << buttonRed) | (1 << buttonBlu) | (1 << buttonGre) | (1 << buttonOra);

	// enable button interrupts
	PCMSK2 |= (1 << PCINT18) | (1 << PCINT19) | (1 << PCINT20) | (1 << PCINT21) | (1 << PCINT22) | (1 << PCINT23);
	
	// LED SETUP
	// setup led decoder outputs
	DDRC |= (1 << ledA) | (1 << ledB) | (1 << ledC);
		
	// enable global interrupts
	sei();
	
	//seed random sequence generator at power on
	seedSequence(randomSeedPtr);
	
	while (1)
	{	
		while (gameState == idle) {
			roundCount = 0;
			//enable button interrupts
			PCICR |= (1 << PCIE2);
			driveOutput(OFF);
			setDisplayValue(roundCount,&disp);
			toneOff();
		}
		while (gameState == start) {
			generateSequence(MAX_SEQ_LENGTH, randomSeedPtr);
			gameState = playSequence;
		}
		while (gameState == playSequence) {
			//disable button interrupts
			PCICR &= ~(1 << PCIE2);
			setDisplayValue(roundCount,&disp);
			displaySequence(roundCount+1, randomSequence);
			gameState = inputSequence;
		}
		while (gameState == inputSequence) {
			//enable button interrupts
			PCICR |= (1 << PCIE2);
			gameState = acceptInput(roundCount+1);
		}
		while (gameState == win) {
			setDisplayValue(roundCount,&disp);
			_delay_ms(100);
			for(int i=0; i<3; i++) {
				driveOutput(PURPLE);
				_delay_ms(200);
				driveOutput(BLUE);
				_delay_ms(200);
				driveOutput(YELLOW);
				_delay_ms(200);
				driveOutput(GREEN);
				_delay_ms(200);
				driveOutput(RED);
				_delay_ms(200);
				driveOutput(ORANGE);
				_delay_ms(200);
			}
			gameState = idle;
		}
		while (gameState == lose) {
			TCCR1A = 0x03; 
			toneOn(0xFF);
			_delay_ms(2500);
			toneOff();
			TCCR1A = 0x00;
			gameState = idle;
		}
	}
	return 0;
	
	
}


void displaySequence(int length, uint8_t sequence[]){
	//loop through and display length of sequence
	for(int i=0; i < length; i++){
		driveOutput(OFF);
		_delay_ms(100);
		driveOutput(sequence[i]);
		_delay_ms(1000);
	}
	driveOutput(OFF);
	_delay_ms(100);
}

enum state acceptInput(uint8_t length){
	
	inputCounter = 0;
	uint8_t i = 0;

	while(i < length) {
		lastInput = OFF;
		while(inputCounter <= 20) {
			_delay_ms(100);  // 100 works good here for play, 1000 for testing
			inputCounter++;
			//setDisplayValue(inputCounter, &disp);
			if(lastInput == randomSequence[i]){
				inputCounter=0;
				i++;
				_delay_ms(100);
				if(length == MAX_SEQ_LENGTH  && i == length) {
					roundCount++;
					_delay_ms(1000);
					driveOutput(OFF);
					_delay_ms(1000);
					return win;
				}
				if(i == length) {
					roundCount++;
					_delay_ms(1000);
					driveOutput(OFF);
					_delay_ms(1000);
					return playSequence;
				}
				break;
			}
			else if(inputCounter == 5) driveOutput(OFF);
			else if(inputCounter >= 20) return lose;
			else if(lastInput != randomSequence[i] && lastInput != OFF) return lose;
		}
		inputCounter=0;
	}
	_delay_ms(500);
	return playSequence;
}


void driveOutput(enum color col) {
	switch (col) {
		case(PURPLE):	// 000
			toneOn(0x80);
			PORTC  &= ~((1 << ledC) | (1 << ledB) | (1 << ledA));
			break;
		case(YELLOW):	// 001
			toneOn(0x70);
			PORTC  |= (1 << ledA);
			PORTC  &= ~((1 << ledB) | (1 << ledC));
			break;
		case(RED):		// 010
			toneOn(0x60);
			PORTC  |= (1 << ledB);
			PORTC  &= ~((1 << ledC) | (1 << ledA));
			break;
		case(BLUE):		// 011
			toneOn(0x50);
			PORTC  |= ((1 << ledB) | (1 << ledA));
			PORTC  &= ~(1 << ledC);
			break;
		case(GREEN):	// 100
			toneOn(0x40);
			PORTC  |= (1 << ledC) ;
			PORTC  &= ~((1 << ledB) | (1 << ledA));
			break;
		case(ORANGE):	// 101
			toneOn(0x30);
			PORTC  |= ((1 << ledC) | (1 << ledA));
			PORTC  &= ~(1 << ledB);
			break;
		case(OFF):		// 111
			PORTC  |= ((1 << ledC) | (1 << ledB) | (1 << ledA));
			toneOff();
			break;
	}
}


void seedSequence(uint8_t *seed){
	*seed = 1;
	uint8_t ADCval;

	ADMUX = 5;         // use ADC5
	ADMUX |= (1 << REFS0);    // use AVcc as the reference
	ADMUX &= ~(1 << ADLAR);   // clear for 10 bit resolution
		
	ADCSRA |= (1 << ADPS2) | (1 << ADPS1) | (1 << ADPS0);    // 128 prescale 
	ADCSRA |= (1 << ADEN);    // Enable the ADC

	ADCSRA |= (1 << ADSC);    // Start the ADC conversion

	while(ADCSRA & (1 << ADSC));      // Waits for ADC to finish conversion

	ADCval = ADCL;
	ADCval = (ADCH << 8) + ADCval;    // ADCH is read so ADC can be updated again
	ADCSRA &= ~(1 << ADEN);  //disable the ADC
	*seed = ADCval;
}

void generateSequence(uint8_t length, uint8_t *seed){
	for(int i=0; i<length; i++) {
		*seed ^= (*seed << 7);
		*seed ^= (*seed >> 5);
		*seed ^= (*seed << 3);
		randomSequence[i] = *seed % 6;
	}
}

void toneOn(uint8_t count)
{	
	OCR1A = count;
	TIMSK1 |= (1 << OCIE1A);
}

void toneOff(void)
{
	// disable timer1 interrupts to stop tone
	TIMSK1 &= (~1 << OCIE1A);
}


ISR(TIMER2_COMPA_vect) {
	displayDigits(&disp);
}

ISR(TIMER1_COMPA_vect)
{
	PORTB ^= (1 << speaker);
}

ISR(PCINT2_vect) {
	if(gameState == idle) gameState = start;
	else if(gameState == inputSequence  && inputCounter != 0) {
		if(!(PIND & (1 << buttonPur))) {
			input = PURPLE;
			lastInput = PURPLE;
		}
		else if(!(PIND & (1 << buttonYel))) {
			input = YELLOW;
			lastInput = YELLOW;
		}
		else if(!(PIND & (1 << buttonRed))) {
			input = RED;
			lastInput = RED;

		}
		else if(!(PIND & (1 << buttonBlu))) {
			input = BLUE;
			lastInput = BLUE;
		}
		else if(!(PIND & (1 << buttonGre))) {
			input = GREEN;
			lastInput = GREEN;
		}
		else if(!(PIND & (1 << buttonOra))) {
			input = ORANGE;
			lastInput = ORANGE;
		}
		else {
			input = OFF;
		}
		driveOutput(input);
	}
}

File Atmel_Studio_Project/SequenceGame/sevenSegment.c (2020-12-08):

/*
 * sevenSegment.c
 *
 * Created: 10/31/2020 11:29:19 PM
 *  Author: golob
 */ 

#include <avr/io.h>
#include "sevenSegment.h"

/*
 * displayDigit function to drive SN74LS47 IC
 * input integer in BCD to drive a common anode 7-seg display
 * PORTC must be used, pins are configurable in struct
 */

void displayDigits(sSegPtr_t disp) {
	int value;
	//ACTIVE LOW PNP
	if(disp->lastDisplayed == disp->digit0) {
		PORTC |= (1 << disp->digit1);
		PORTC &= ~(1 << disp->digit0);
		value = disp->digitValue0;
		disp->lastDisplayed = disp->digit1;
	}
	else  {
		PORTC |= (1 << disp->digit0);
		PORTC &= ~(1 << disp->digit1);
		value = disp->digitValue1;
		disp->lastDisplayed = disp->digit0;
	}
	
	switch (value) {
		case(0): 
			PORTB  &= ~((1 << disp->pinA) | (1 << disp->pinB) | (1 << disp->pinC) | (1 << disp->pinD));
			break;
		case(1):
			PORTB  |= ((1 << disp->pinA));
			PORTB  &= ~((1 << disp->pinB) | (1 << disp->pinC) | (1 << disp->pinD));
			break;
		case(2):
			PORTB  |= ((1 << disp->pinB));
			PORTB  &= ~((1 << disp->pinA) | (1 << disp->pinC) | (1 << disp->pinD));
			break;
		case(3):
			PORTB  |= ((1 << disp->pinA) |  (1 << disp->pinB));
			PORTB  &= ~((1 << disp->pinC) | (1 << disp->pinD));
			break;
		case(4):
			PORTB  |= ((1 << disp->pinC));
			PORTB  &= ~((1 << disp->pinA) | (1 << disp->pinB) |  (1 << disp->pinD));
			break;
		case(5):
			PORTB  |= ((1 << disp->pinA) |  (1 << disp->pinC));
			PORTB  &= ~((1 << disp->pinB) | (1 << disp->pinD));
			break;
		case(6):
			PORTB  |= ((1 << disp->pinB) |  (1 << disp->pinC));
			PORTB  &= ~((1 << disp->pinA) | (1 << disp->pinD));
			break;
		case(7):
			PORTB  |= ((1 << disp->pinA) | (1 << disp->pinB) | (1 << disp->pinC));
			PORTB  &= ~((1 << disp->pinD));
			break;
		case(8):
			PORTB  |= ((1 << disp->pinD));
			PORTB  &= ~((1 << disp->pinA) | (1 << disp->pinB) | (1 << disp->pinC));
			break;
		case(9):			
			PORTB  |= ((1 << disp->pinA) |  (1 << disp->pinD));
			PORTB  &= ~((1 << disp->pinB) | (1 << disp->pinC));
			break;
		default:
			PORTB |= ((1 << disp->pinA) | (1 << disp->pinB) | (1 << disp->pinC) | (1 << disp->pinD));
			break;
	}
}

void countValueUp(sSegPtr_t disp){
	if (disp->digitValue1 == 9 && disp->digitValue0 == 9) {
		disp->digitValue1 = 0;
		disp->digitValue0 = 0;
	}
	else if(disp->digitValue0 == 9){
		disp->digitValue1 ++;
		disp->digitValue0 = 0;
	}
	else disp->digitValue0++;
}

void setDisplayValue(uint8_t value, sSegPtr_t disp) {
		disp -> digitValue0 = value % 10;
		disp -> digitValue1 = (value / 10);
}

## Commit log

2020-11-02 added preliminarySchematic
    [preliminarySchematic.sch]
2020-11-02 Added preliminary schematic and breadboard
2020-11-02 added audio amp and speaker
    [preliminarySchematic.sch]
2020-11-09 added preliminary PCB layout
    [sequenceGamePreliminary.brd]
2020-11-12 added preliminary bill of materials
    [Bill of Materials.xlsx]
2020-11-19 added rev 1.0 of schematic and board sent to OSH Park
    [sequenceGameRev1-0.brd, sequenceGameRev1-0.sch]
2020-11-19 added images of rev 1.0 schematic and board
2020-11-19 updated readme with rev 1.0 board and schematic
2020-12-02 updated schematic to new color arrangement
2020-12-02 Color update on schematic

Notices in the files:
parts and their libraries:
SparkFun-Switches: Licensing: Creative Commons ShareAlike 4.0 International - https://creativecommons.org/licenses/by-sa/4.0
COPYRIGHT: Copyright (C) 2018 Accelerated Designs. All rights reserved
